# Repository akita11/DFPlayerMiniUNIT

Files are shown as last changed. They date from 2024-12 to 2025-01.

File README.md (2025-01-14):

# DFPlayerMiniUNIT

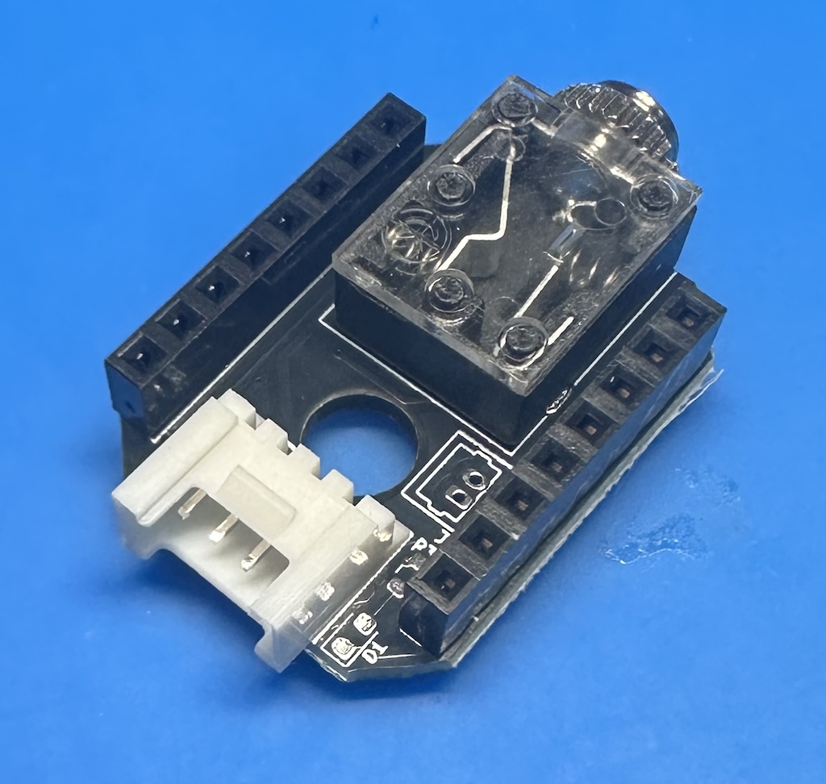
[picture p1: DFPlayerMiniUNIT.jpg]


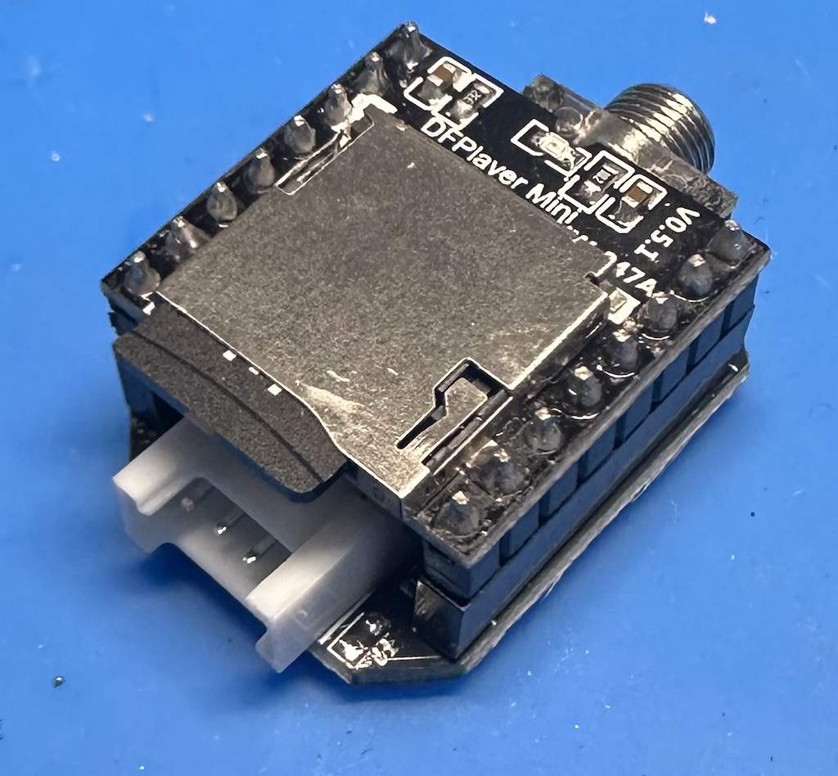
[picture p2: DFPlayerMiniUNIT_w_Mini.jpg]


※当初掲載していた"DFPlayerMini"をとりつけた状態の写真で、DFPlayerMiniの向きが逆になっていました。こちらの写真が正しいです。

DFRobotの音声プレーヤモジュール[DFPlayer(DFPlayerMini)](https://www.switch-science.com/products/4291)をGrove端子を接続して制御できるモジュールです。Grove端子からシリアル(UART)通信で音声再生などを制御することができます。UIFlow(v1)用のブロックもあります。

※DFPlayerMiniは付属していません

## 使い方（接続方法）

以下のようにスピーカやアンプを接続し、Grove端子からの制御で音声を再生します。

### アンプ付きスピーカに接続する場合

3.5mmジャック（ステレオ：上部中央）に3.5mmステレオケーブル等でアンプに接続します。

### スピーカを直接接続する場合

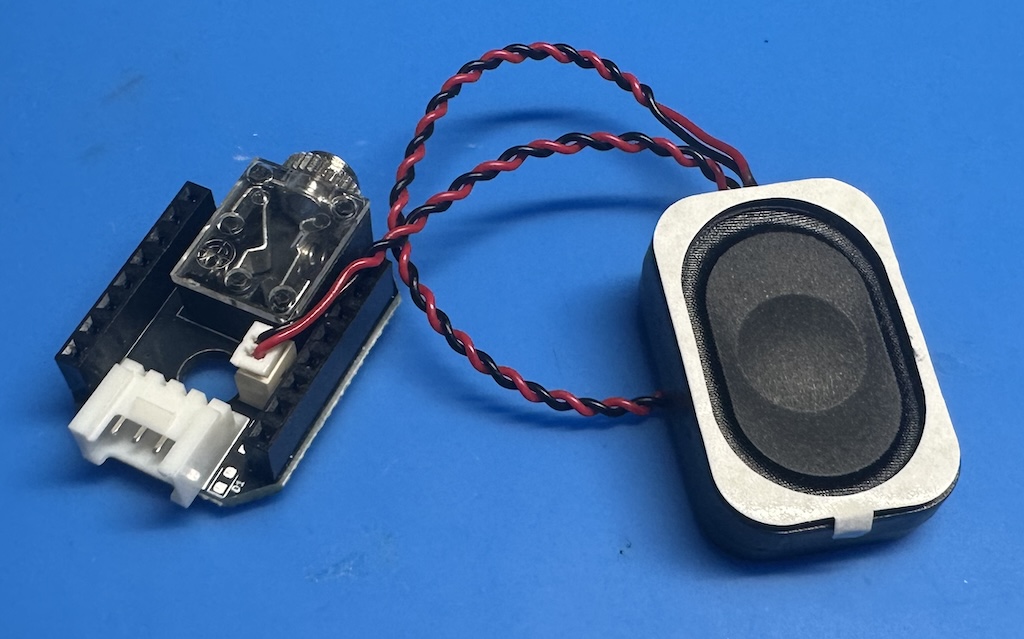
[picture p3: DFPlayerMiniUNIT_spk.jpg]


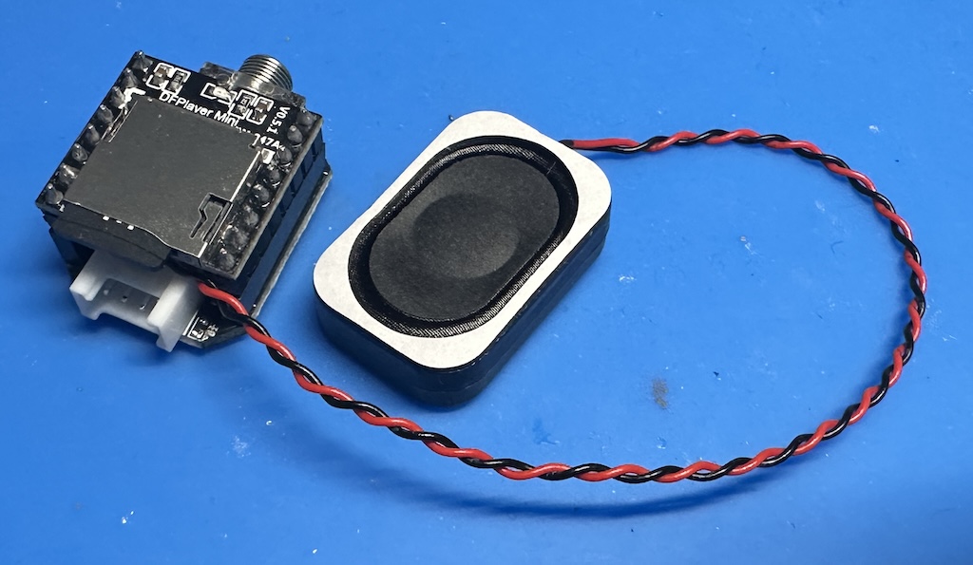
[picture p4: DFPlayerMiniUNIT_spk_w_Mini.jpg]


基板中央部の1.25mmピッチコネクタ(Molex 53047-0210用)にスピーカを接続します。市販の小型スピーカ（M5Stack本体に使われているものなど。AliExpressやTaobaoでも同等品があります）を接続することができます。

※当初掲載していた"DFPlayerMini"をとりつけた状態の写真で、DFPlayerMiniの向きが逆になっていました。こちらの写真が正しいです。

### 3.5mmジャックに直接スピーカを接続する方法

3.5mmジャックに直接スピーカを接続することもできます。その場合は、基板裏面のハンダジャンパを以下のように修正してください。

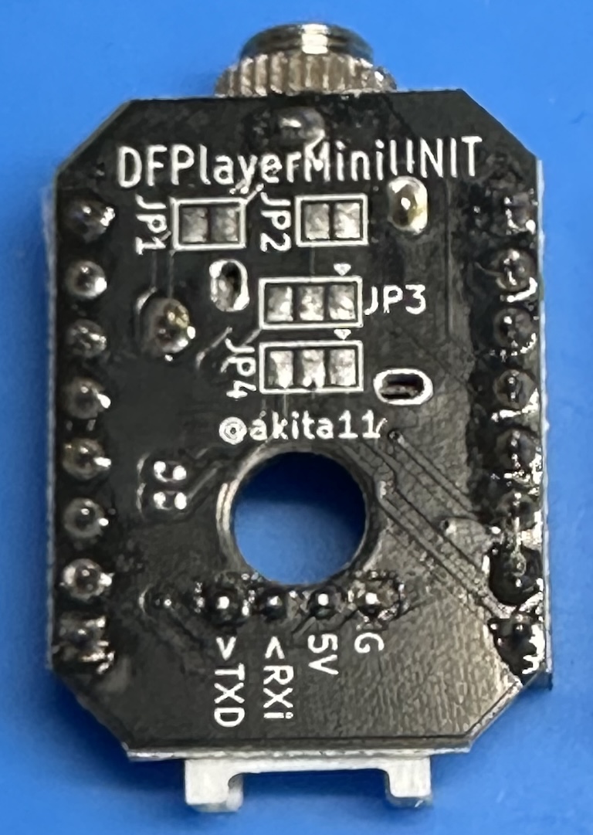
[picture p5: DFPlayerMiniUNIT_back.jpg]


- JP1をカット
- JP2・JP3の中央と△マーク側をカットし、中央と反対側（△マークがない側）をショート

## 使い方（ソフトウエア）

あらかじめ、microSDカードに使用する音声データ（*.mp3等）をコピーしておき、それをDFPlayerMiniにさしておきます。（このときコピーした順番が、再生時に使用する「曲番号」になります）

### UIFlow(v1)での使い方

「DFPlayerMini.m5b」をダウンロードし、UIFlow(v1)の"Custom"の"Open *.m5b"からこのファイルを指定すると、Init、Play、Volume、Stopの4つのブロックを使用できます。

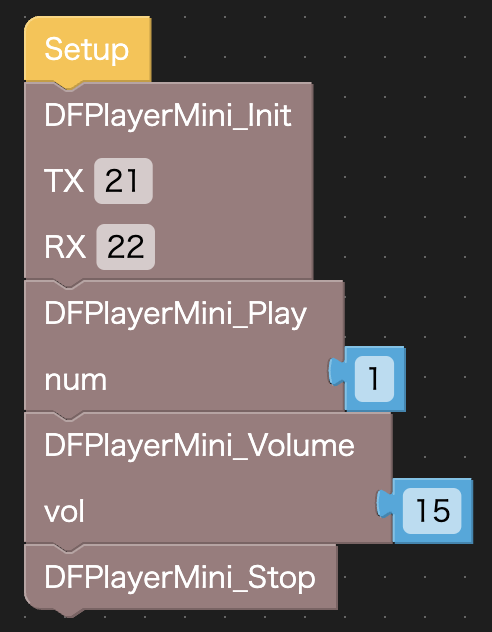
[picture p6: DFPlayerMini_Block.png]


- DFPlayerMini_Init : 初期化。最初に1回だけ読み出します。"TX"と"RX"には、使用するGroveポート・マイコン本体にあわせて、使用するピン番号を指定します。例えば、M5StackBasicのPortA（本体の赤いコネクタ）の場合は、上図のようにTX=21、RX=22を指定します。M5StackCore2のPortAの場合は、TX=32、RX=33となります。
- DFPlayerMini_Play : numに指定した「曲番号」の音声を再生します。
- DFPlayerMini_Volume : volに指定した音量に設定します。
- DFPlayerMini_Stop : 再生中の音声を停止します。

### その他のソフトウエアでの使い方

Arduino用にはライブラリがあるようなので、そちらを使ってもOKです。
あるいは、DFPlayerMiniのデータシート等を参考に、制御コマンドを送信して使用してください。

## Author

Junichi Akita (@akita11) / akita@ifdl.jp

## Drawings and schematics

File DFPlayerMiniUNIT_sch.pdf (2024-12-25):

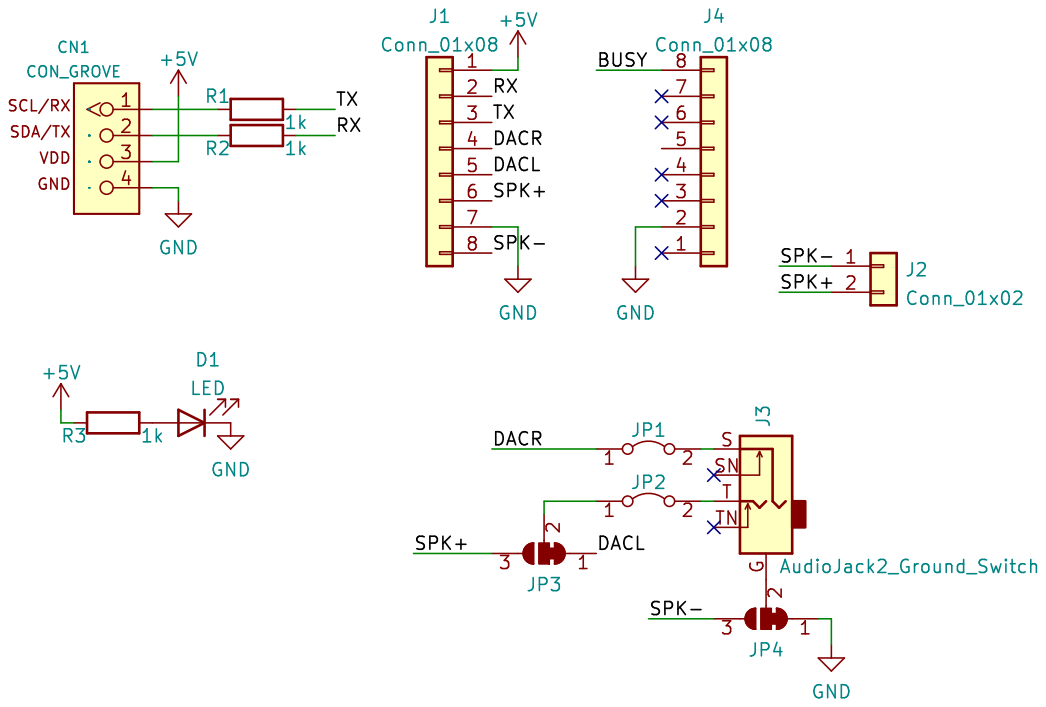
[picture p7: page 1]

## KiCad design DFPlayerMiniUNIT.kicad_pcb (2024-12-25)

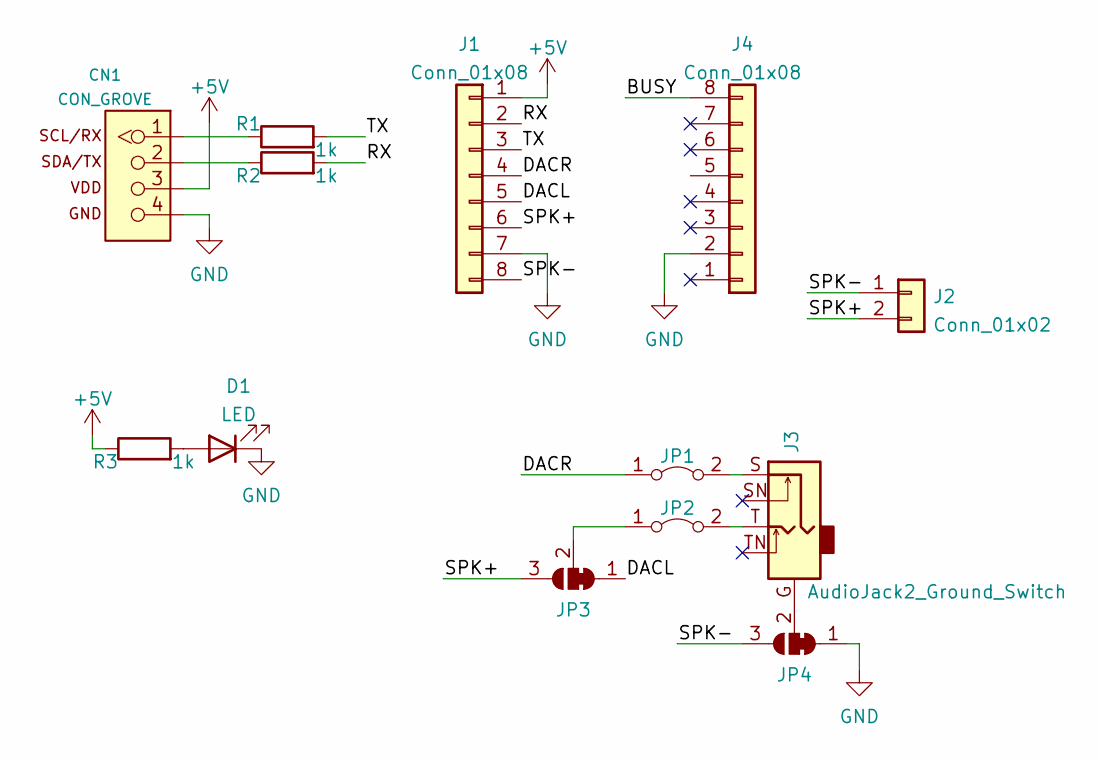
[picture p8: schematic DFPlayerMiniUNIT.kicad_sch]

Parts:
CN1: CON_GROVE; CON_GROVE_H
D1: LED; LED_0603_1608Metric
J1, J4: Conn_01x08; PinSocket_1x08_P2.54mm_Vertical
J2: Conn_01x02; Molex_PicoBlade_53047-0210_1x02_P1.25mm_Vertical
J3: AudioJack2_Ground_Switch; CON_AJ-1780
JP1, JP2: Jumper_2_Bridged; SolderJumper-2_P1.3mm_Bridged_Pad1.0x1.5mm
JP3, JP4: SolderJumper_3_Bridged12; SolderJumper-3_P1.3mm_Bridged12_Pad1.0x1.5mm
R1, R2, R3: 1k; R_0603_1608Metric

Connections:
+5V: CN1.3, J1.1, R3.1
/BUSY: J4.8
/DACL: J1.5, JP3.1 (A)
/DACR: J1.4, JP1.1 (A)
/RX: J1.2, R2.2
/SPK+: J1.6, J2.2, JP3.3 (B)
/SPK-: J1.8, J2.1, JP4.3 (B)
/TX: J1.3, R1.2
GND: CN1.4, D1.1 (K), J1.7, J4.2, JP4.1 (A)
unnamed: CN1.1, R1.1
unnamed: CN1.2, R2.1
unnamed: D1.2 (A), R3.2
unnamed: J3.G, JP4.2 (C)
unnamed: J3.S, JP1.2 (B)
unnamed: J3.T, JP2.2 (B)
unnamed: JP2.1 (A), JP3.2 (C)

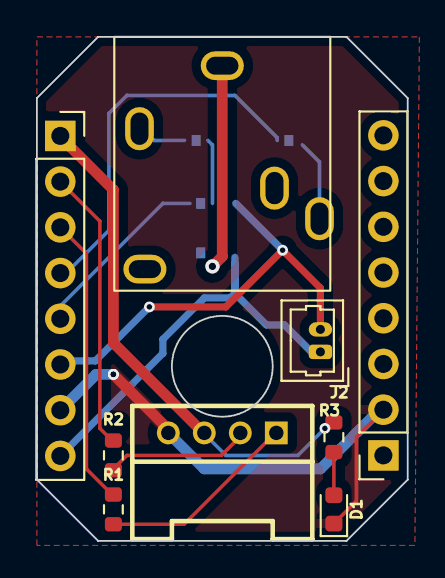
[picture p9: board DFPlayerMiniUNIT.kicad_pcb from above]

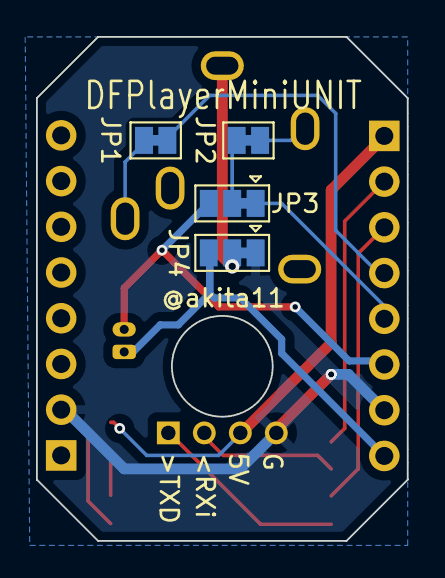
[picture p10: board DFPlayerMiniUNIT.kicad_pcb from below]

Board: 2 copper layers, 20.6 x 28.0 mm, 13 parts (4 on the bottom side), 15 nets.
